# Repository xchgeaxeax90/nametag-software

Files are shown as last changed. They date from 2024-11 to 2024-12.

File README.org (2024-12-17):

#+title: Wisp Light-up Nametag

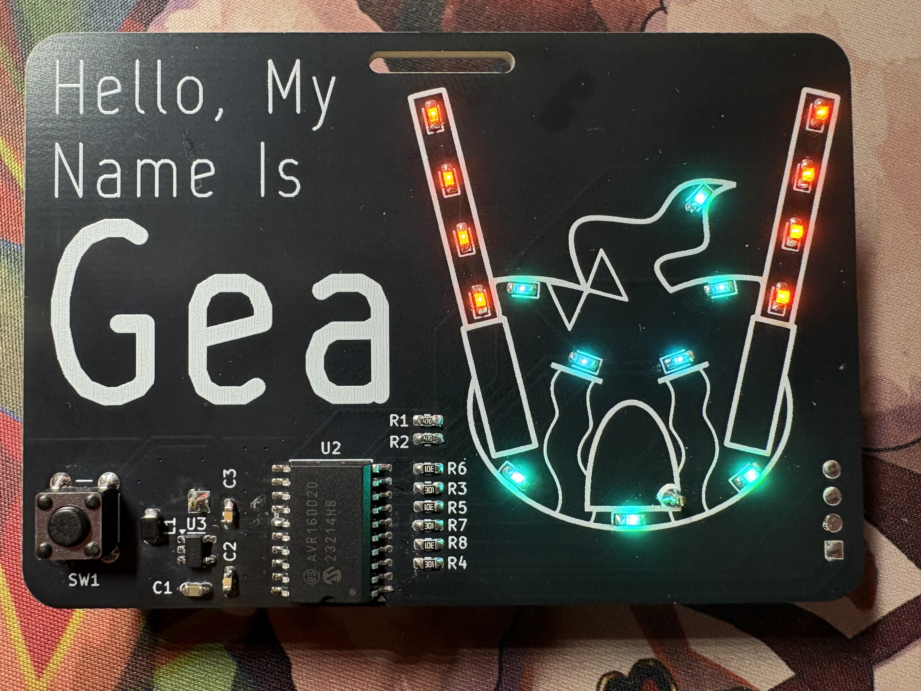
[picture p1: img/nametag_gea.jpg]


This repository contains the PCB design and software for the light up
nametag I gave out at AWA. Gerbers for the blank badge I gave out are
available, and the Kicad project is available for you to modify the
name silkscreened onto the PCB if you would like as well.

But first:
** Crushing Your Expectations
This project involves PCB manufacturing, surface mount soldering, and
flashing firmware onto a microcontroller. While I am able to offer
guidance and suggestions on how to do these things, this is not a step
by step tutorial on how to build your own badge. If you have never
soldered before and have not worked with a bare metal microcontroller,
this project may not be for you.

** PCB
PCBs were ordered from JLCPCB. If you would like to build the blank
nametag, take ~pcb_outputs/nametag_blank.zip~ and upload it to
[[https://jlcpcb.com/][JLCPCB's PCB quote page]]

I would recommend selecting "Black" for PCB color, "Remove Mark" for
Mark on PCB, and leaving everything else default.
The PCB quote should come out to between $2-$4. Pick a shipping option
and order.

*** Custom PCBs
 - Download and install [[https://www.kicad.org/][Kicad]]
 - Open Kicad, then open ~pcb/nametag.kicad_pro~.
 - Click the green button labeled "PCB Editor"
 - Double click on the text on the left to edit it
   - When done, make sure any text you modified or added is on the
 F.Silkscreen layer, it should appear a teal blue.
 - Click File->Fabrication Outputs->Gerbers...
   - Select a directory to export the PCB data to in "Output Directory"
   - Leave the all the checkboxes as they are
   - Click "Plot" on the bottom right
   - Before closing the dialogue box, click "Generate Drill Files..."
     on the bottom row
   - Leave all settings on the new dialogue as default, click
     "Generate Drill File"
   - Close both dialogue boxes
 - Zip up the directory you created in the previous steps. It should
   contain the following:

#+begin_src
nametag-B_Cu.gbr
nametag-B_Mask.gbr
nametag-B_Paste.gbr
nametag-B_Silkscreen.gbr
nametag-Edge_Cuts.gbr
nametag-F_Cu.gbr
nametag-F_Mask.gbr
nametag-F_Paste.gbr
nametag-F_Silkscreen.gbr
nametag-job.gbrjob
nametag-NPTH.drl
nametag-PTH.drl
#+end_src

 - Upload the zip to JLCPCB as described above for the blank PCB

** Parts
An interactive HTML BOM is available in pcb/bom/

My digikey order export is below if that is better for some people.

| Index | DigiKey Part #                  | Manufacturer Part Number | Description                      | Quantity |
|-------+---------------------------------+--------------------------+----------------------------------+----------|
|     1 | 150-AVR16DD20-I/SO-ND           | AVR16DD20-I/SO           | IC MCU 8BIT 16KB FLASH 20SOIC    |        1 |
|     2 | SMLD12E3N1WT86CT-ND             | SMLD12E3N1WT86           | LED BLUE-GREEN DIFFUSED 1608 SMD |        6 |
|     3 | 160-1434-1-ND                   | LTST-C190KFKT            | LED ORANGE CLEAR CHIP SMD        |        8 |
|     4 | 2223-TS02-66-43-BK-160-LCR-D-ND | TS02-66-43-BK-160-LCR-D  | SWITCH TACTILE SPST-NO 0.05A 12V |        1 |
|     5 | 732-4971-1-ND                   | 150060GS75000            | LED GREEN CLEAR 0603 SMD         |        6 |
|     6 | 36-2466-ND                      | 2466                     | BATTERY HOLDER AAA PC PIN        |        1 |
|     7 | 846-SMLD12E2N1WT86CT-ND         | SMLD12E2N1WT86           | LED BLUE-GREEN DIFFUSED 1608 SMD |        2 |
|     8 | 296-52012-1-ND                  | TPS613226ADBVR           | IC REG BOOST 3.6V 1.6A SOT23-5   |        1 |
|     9 | 4713-GMC10X5R226M10NTCT-ND      | GMC10X5R226M10NT         | CAP0603 X5R 22UF 20% 10V         |        1 |
|    10 | 3526-WIP201612S-2R2MLDGCT-ND    | WIP201612S-2R2MLDG       | POWER INDUCTOR 2016 2.2UH 20% DC |        1 |
|    11 | 1292-WR06X470JTLCT-ND           | WR06X470 JTL             | RES 47 OHM 5% 1/10W 0603         |        2 |
|    12 | 300 Ohm 0603 Resistor           | Pick one                 | It doesn't matter                |        6 |
|    13 | 0.1uF 0603 X7R Capacitor        | Pick one                 | At least 6V                      |        2 |

The digikey order above lists 3 green LEDs:
 - SMLD12E3N1WT86 in index 2 - 496nm LED
 - SMLD12E2N1WT86 in index 7 - 505nm LED
 - 150060GS75000  in index 5 - 520nm LED

I originally bought 3 different types because I didn't know what color
would look good. My preference was to have the 505nm LEDs on the
border of the wisp as they look closest to a mint green. The 496nm
LEDs are closer to a cyan and work well in the eye positions. the
520nm LEDs are a cheaper alternative to 505nm LEDs, but are a much
brighter and harsher green than the 505nm LEDs.

Consider what color LEDs you want where, just keep in mind you will
need 8 total to fill out the wisp

The BOM above also lists out some jelly bean 300 ohm resistors and
0.1uF capacitors, both in 0603 size. If you don't have those already,
pick the cheapest ones

Finally, pay attention to your electronic distributor's price breaks,
especially when ordering for only one nametag. For things like LEDs,
resistors, and capacitors, it's often cheaper to order 10 than 4-9,
and you are quite likely to accidentally lose one or two during
assembly. It also would be a good idea to order an extra TPS613226
boost converter in case you fry it putting the battery in wrong (ask
how I know)

** Assembly

Assemble everything according to the interactive BOM in ~pcb/bom~. Pay
attention to the LED polarity. The green LEDs have a little arrow on
the back, that needs to point towards the closed end on each of the
LED footprints. Similarly, the orange LEDs have a little extra tab of
metal on the back, that again needs to face the closed end on the
silkscreen for each of the LED footprints.

Make sure to attach the battery holder to the back side of the PCB,
and ensure it's facing the right polarity

Do not populate the J1 connector, for programming it's far easier to
just jam wires into the holes for a minute instead of worrying about
desoldering a programming header when you want to actually wear the badge

** Programming

The AVR16DD used in this project uses Microchip's new Universal
Programming and Debug Interface (UPDI). While very convenient as it
only uses one pin, programmers for it are not super common. However,
it's not too difficult to build your own:

 - If you have an arduino or other older AVR development board: https://github.com/ElTangas/jtag2updi
   - Be careful with this as the nametag circuit runs on 3.6V, not
     5V. You may need a level shifter and definitely at least need the
     resistor shown in this guide
 - If you have an extra $7, this looks pretty convenient: https://www.adafruit.com/product/5879
 - If you have an FTDI, CP2102, CH340, or other UART dongle, you can
   build an UPDI programmer using the information here https://github.com/SpenceKonde/AVR-Guidance/blob/master/UPDI/jtag2updi.md
   - This is what I did here, I used an FT232H cable with a 5k
     resistor between FT232H TX and the UPDI pin of the
     microcontroller. FT232H RX is directly connected to the UPDI pin
     of the microcontroller
   - Pay attention to the voltage levels output by the UART dongle, as
     again this circuit runs on 3.6V not 5V.

Connect the UPDI pin to the topmost pin of J1 (Pin 4), and ground to
the second pin from the top of J1 (Pin 3)

Download and install [[https://github.com/avrdudes/avrdude][avrdude]]

Navigate to the src/ folder

Run:

#+begin_src
avrdude -c serialupdi -P /dev/ttyUSB0 -p avr16dd20 -B 115200 -U flash:w:main.hex:i
#+end_src

Replace ~-c serialupdi~ with ~-c jtag2updi~ if using the arduino updi
method.
Replace ~-P /dev/ttyUSB0~ with the path to your serial port
Lower ~-B 115200~ if having issues with flaky programming

If successful, your badge should begin flashing

Some method of affixing the nametag to your body will be needed. A
slot is available on the top of the PCB for affixing to a
lanyard. Alternatively (this is what I did) a
[[https://www.ebay.com/itm/183618333854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][magnetic nametag holder]] or pin should be used

** Modifying the source code
LMAO good luck

Install
[[https://avrdudes.github.io/avr-libc/avr-libc-user-manual/install_tools.html][avr-gcc,
avr-binutils, and avr-libc]] -
these will come preinstalled with the arduino IDE if you can figure
out how to access them.

Install [[https://www.gnu.org/software/make/][Make]]. This may come with
Git bash on windows and is almost certainly in your package manager on
Linux.

Navigate to ~src/~ and run ~make~

Run ~make prog~ to program the microcontroller

** Operation

To cycle animations, quickly tap the button

To change the brightness, hold the button for ~3 seconds and
release. The LEDs should turn on continuously. Tap the button to
change the brightness, then press and hold for ~3 seconds and release
again to go back to the animation mode

To turn off, push and hold the button until the LEDs turn off

To turn back on, tap the button again

When storing for a long period of time (weeks, months), it is
recommended to remove or disconnect the battery. The system does not
actually shut off when powered off, instead the microcontroller turns
off all the LEDs and enters into a deep sleep mode. However, the boost
converter powering the circuit remains on, drawing a tiny amount of
power. Over a long period of time (months), this will drain the battery.

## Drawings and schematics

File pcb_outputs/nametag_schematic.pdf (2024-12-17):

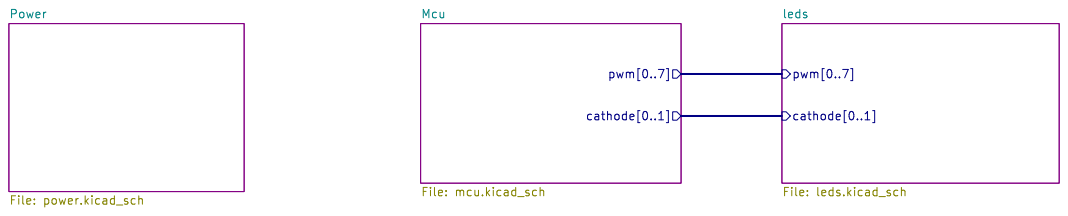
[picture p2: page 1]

cathode[0..1] Mcu File: mcu.kicad_sch Power File: power.kicad_sch

Id: 1/4 Title: File: nametag.kicad_sch Sheet: /

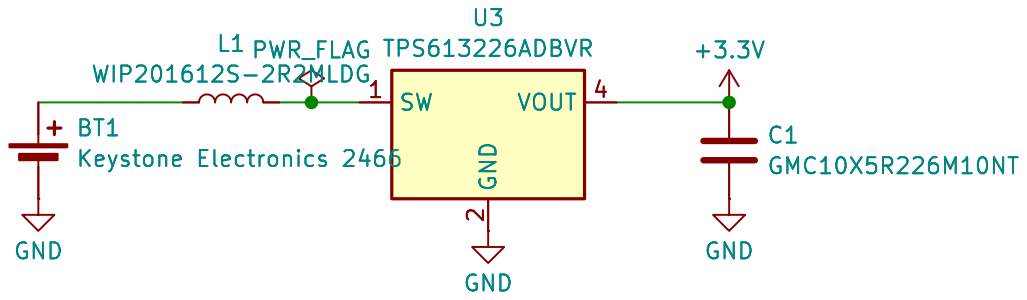
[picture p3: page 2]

Id: 2/4 Title: File: power.kicad_sch Sheet: /Power/

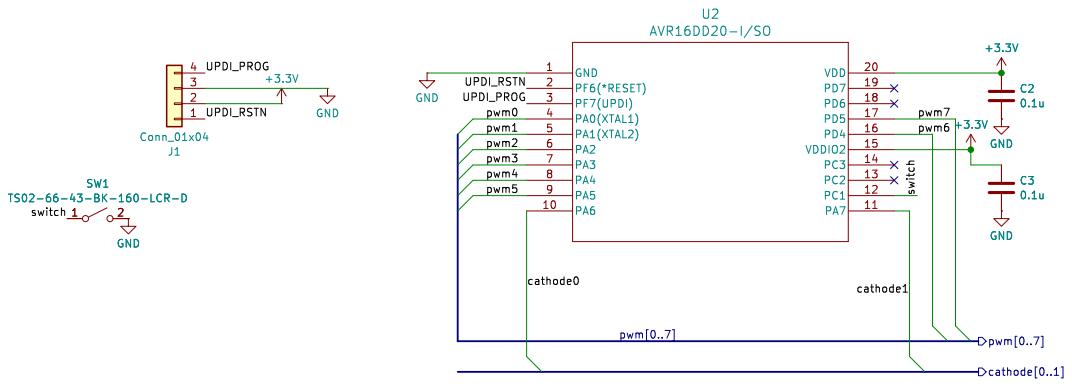
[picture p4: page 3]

Id: 3/4 Title: File: mcu.kicad_sch Sheet: /Mcu/

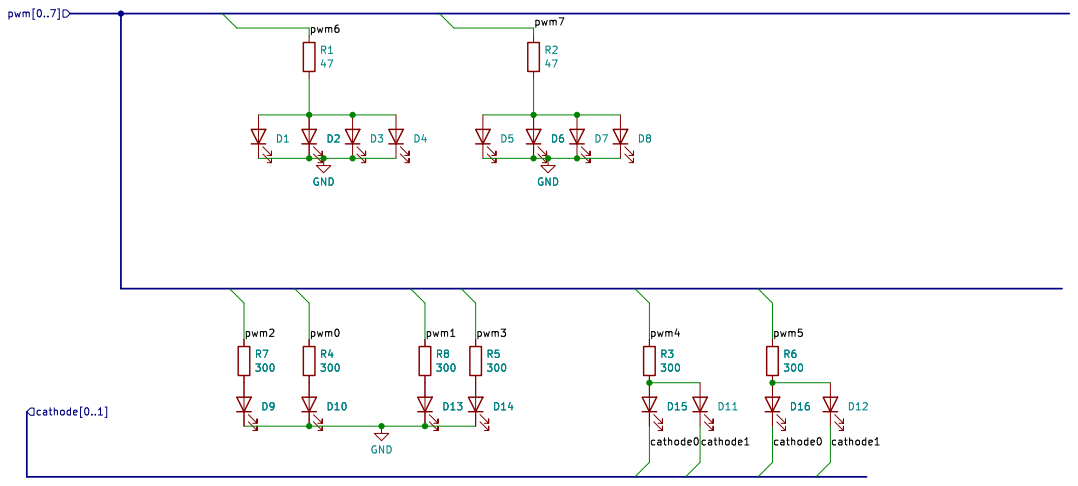
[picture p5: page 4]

Id: 4/4 Title: File: leds.kicad_sch Sheet: /leds/ R3

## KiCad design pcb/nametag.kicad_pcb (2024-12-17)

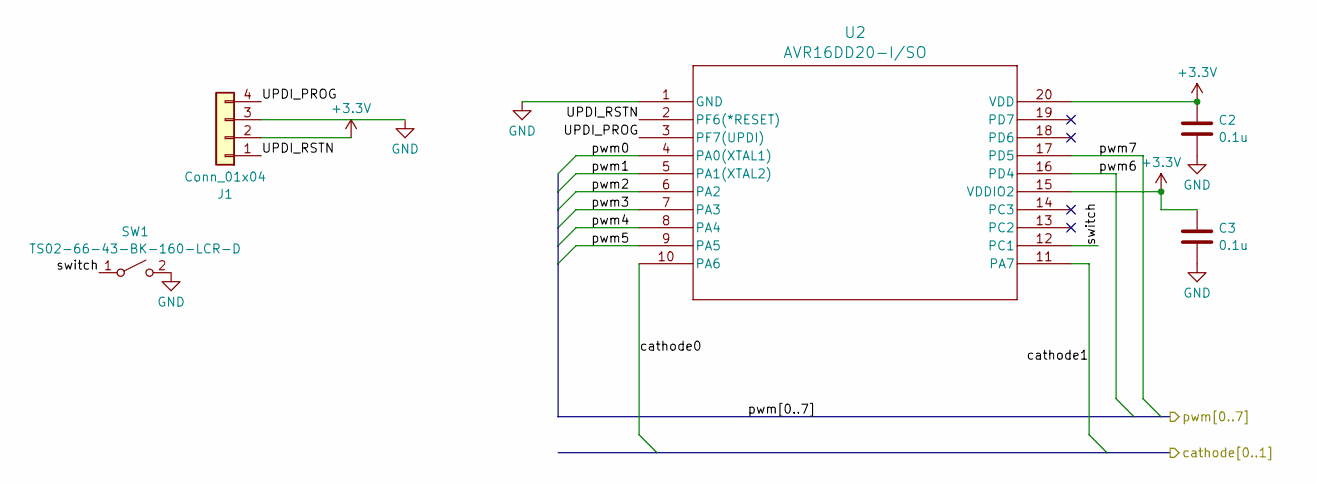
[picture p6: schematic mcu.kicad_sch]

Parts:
C2, C3: 0.1u; C_0603_1608Metric_Pad1.08x0.95mm_HandSolder
J1: Conn_01x04; PinSocket_1x04_P2.54mm_Vertical
SW1: TS02-66-43-BK-160-LCR-D; SW_PUSH_6mm_H4.3mm
U2: AVR16DD20-I/SO; SOIC-20W_7.5x12.8mm_P1.27mm

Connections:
+3.3V: C2.1, C3.1, J1.2, U2.15 (VDDIO2), U2.20 (VDD); also elsewhere on the board
/Mcu/UPDI_PROG: J1.4, U2.3 (PF7(UPDI))
/Mcu/UPDI_RSTN: J1.1, U2.2 (PF6(*RESET))
/Mcu/cathode0: U2.10 (PA6); also elsewhere on the board
/Mcu/cathode1: U2.11 (PA7); also elsewhere on the board
/Mcu/pwm0: U2.4 (PA0(XTAL1)); also elsewhere on the board
/Mcu/pwm1: U2.5 (PA1(XTAL2)); also elsewhere on the board
/Mcu/pwm2: U2.6 (PA2); also elsewhere on the board
/Mcu/pwm3: U2.7 (PA3); also elsewhere on the board
/Mcu/pwm4: U2.8 (PA4); also elsewhere on the board
/Mcu/pwm5: U2.9 (PA5); also elsewhere on the board
/Mcu/pwm6: U2.16 (PD4); also elsewhere on the board
/Mcu/pwm7: U2.17 (PD5); also elsewhere on the board
/Mcu/switch: SW1.1 (A), U2.12 (PC1)
GND: C2.2, C3.2, J1.3, SW1.2 (B), U2.1 (GND); also elsewhere on the board

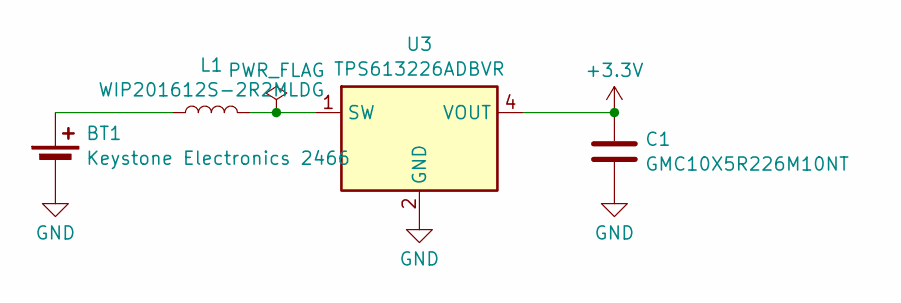
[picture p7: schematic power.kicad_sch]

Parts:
BT1: Keystone Electronics 2466; BatteryHolder_Keystone_2466_1xAAA
C1: GMC10X5R226M10NT; C_0603_1608Metric_Pad1.08x0.95mm_HandSolder
L1: WIP201612S-2R2MLDG; L_0805_2012Metric_Pad1.15x1.40mm_HandSolder
U3: TPS613226ADBVR; SOT-23-5

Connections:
+3.3V: C1.1, U3.4 (VOUT); also elsewhere on the board
GND: BT1.2 (-), C1.2, U3.2 (GND); also elsewhere on the board
unnamed: BT1.1 (+), L1.1
unnamed: L1.2, U3.1 (SW)

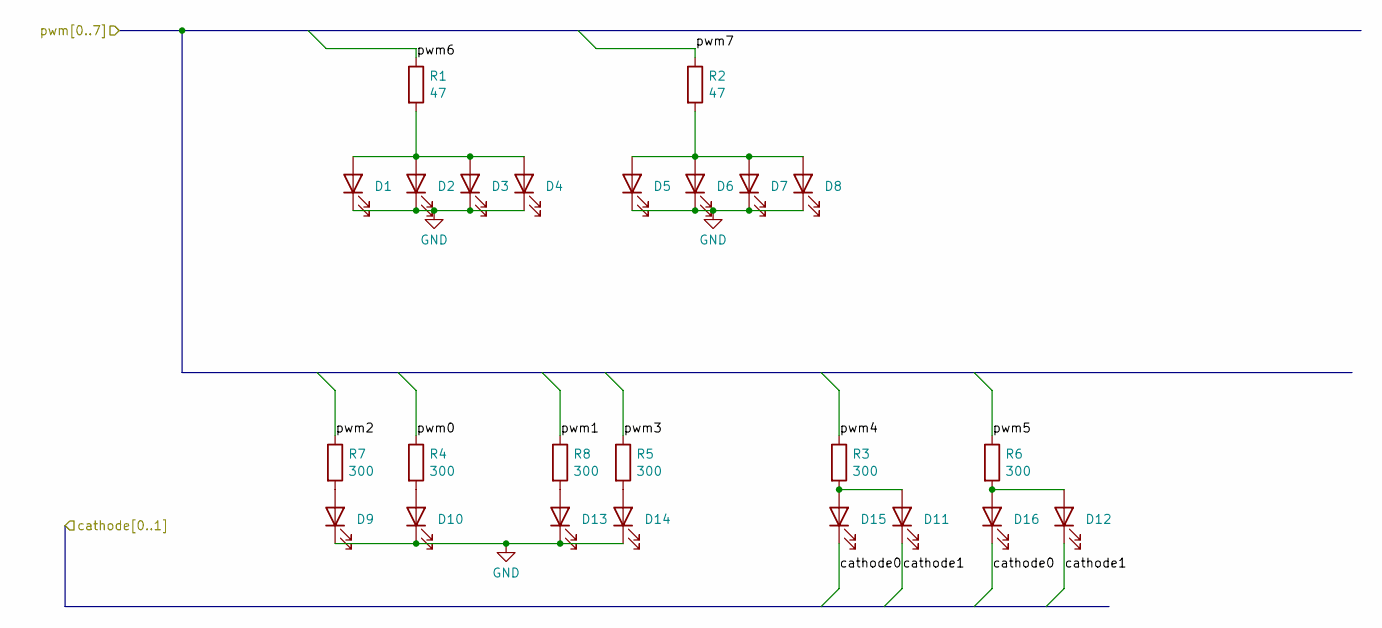
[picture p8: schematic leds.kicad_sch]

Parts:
D1, D2, D3, D4, D5, D6, D7, D8: LTST-C190KFKT; LED_0603_1608Metric_Pad1.05x0.95mm_HandSolder
D9, D10, D11, D12, D13, D14: SMLD12E3N1WT86; LED_0603_1608Metric_Pad1.05x0.95mm_HandSolder
D15, D16: SMLD12E2N1WT86; LED_0603_1608Metric_Pad1.05x0.95mm_HandSolder
R1, R2: 47; R_0603_1608Metric_Pad0.98x0.95mm_HandSolder
R3, R4, R5, R6, R7, R8: 300; R_0603_1608Metric_Pad0.98x0.95mm_HandSolder

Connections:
/Mcu/cathode0: D15.1 (K), D16.1 (K); also elsewhere on the board
/Mcu/cathode1: D11.1 (K), D12.1 (K); also elsewhere on the board
/Mcu/pwm0: R4.1; also elsewhere on the board
/Mcu/pwm1: R8.1; also elsewhere on the board
/Mcu/pwm2: R7.1; also elsewhere on the board
/Mcu/pwm3: R5.1; also elsewhere on the board
/Mcu/pwm4: R3.1; also elsewhere on the board
/Mcu/pwm5: R6.1; also elsewhere on the board
/Mcu/pwm6: R1.1; also elsewhere on the board
/Mcu/pwm7: R2.1; also elsewhere on the board
GND: D1.1 (K), D2.1 (K), D3.1 (K), D4.1 (K), D5.1 (K), D6.1 (K), D7.1 (K), D8.1 (K), D9.1 (K), D10.1 (K), D13.1 (K), D14.1 (K); also elsewhere on the board
unnamed: D1.2 (A), D2.2 (A), D3.2 (A), D4.2 (A), R1.2
unnamed: D5.2 (A), D6.2 (A), D7.2 (A), D8.2 (A), R2.2
unnamed: D9.2 (A), R7.2
unnamed: D10.2 (A), R4.2
unnamed: D11.2 (A), D15.2 (A), R3.2
unnamed: D12.2 (A), D16.2 (A), R6.2
unnamed: D13.2 (A), R8.2
unnamed: D14.2 (A), R5.2

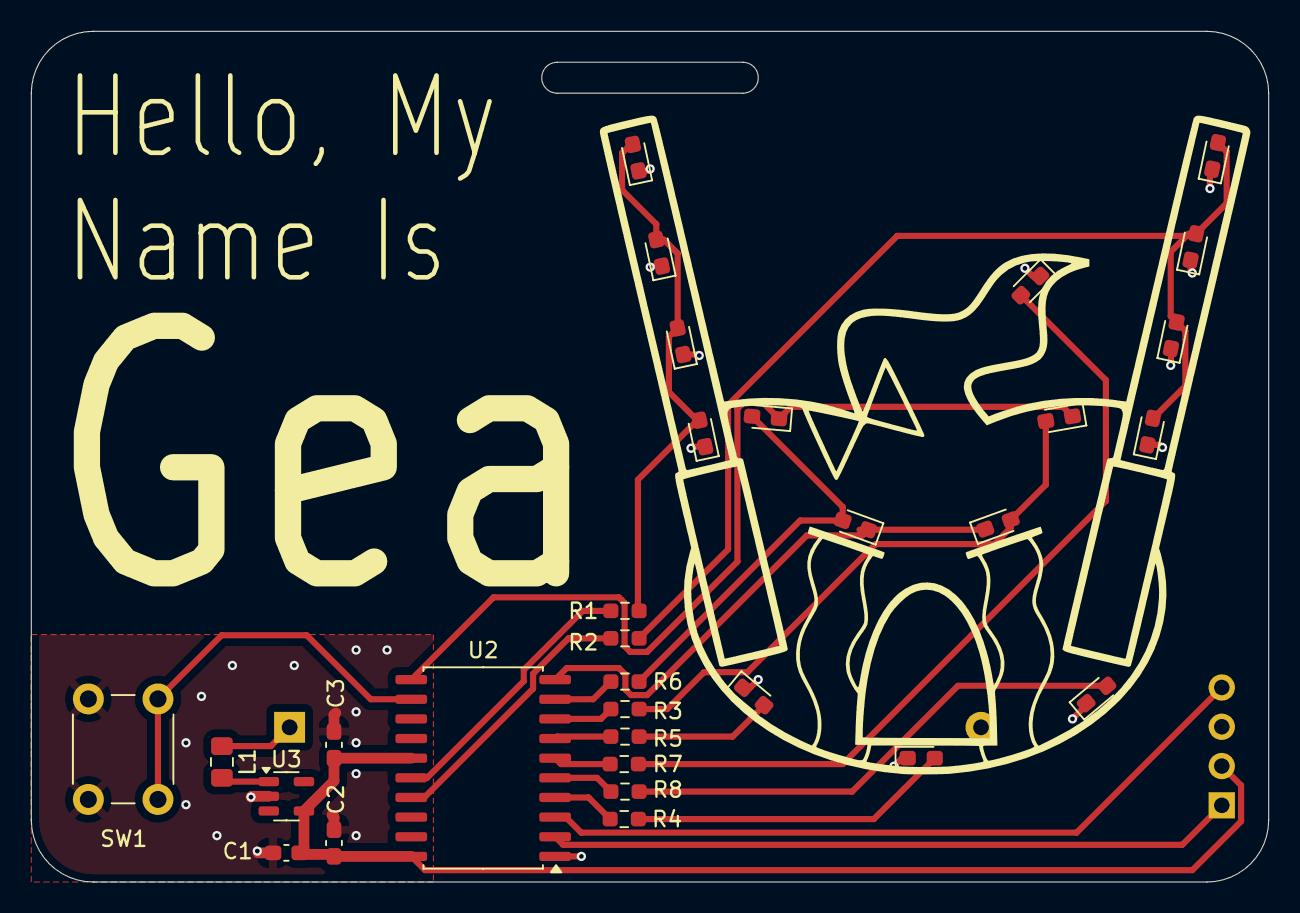
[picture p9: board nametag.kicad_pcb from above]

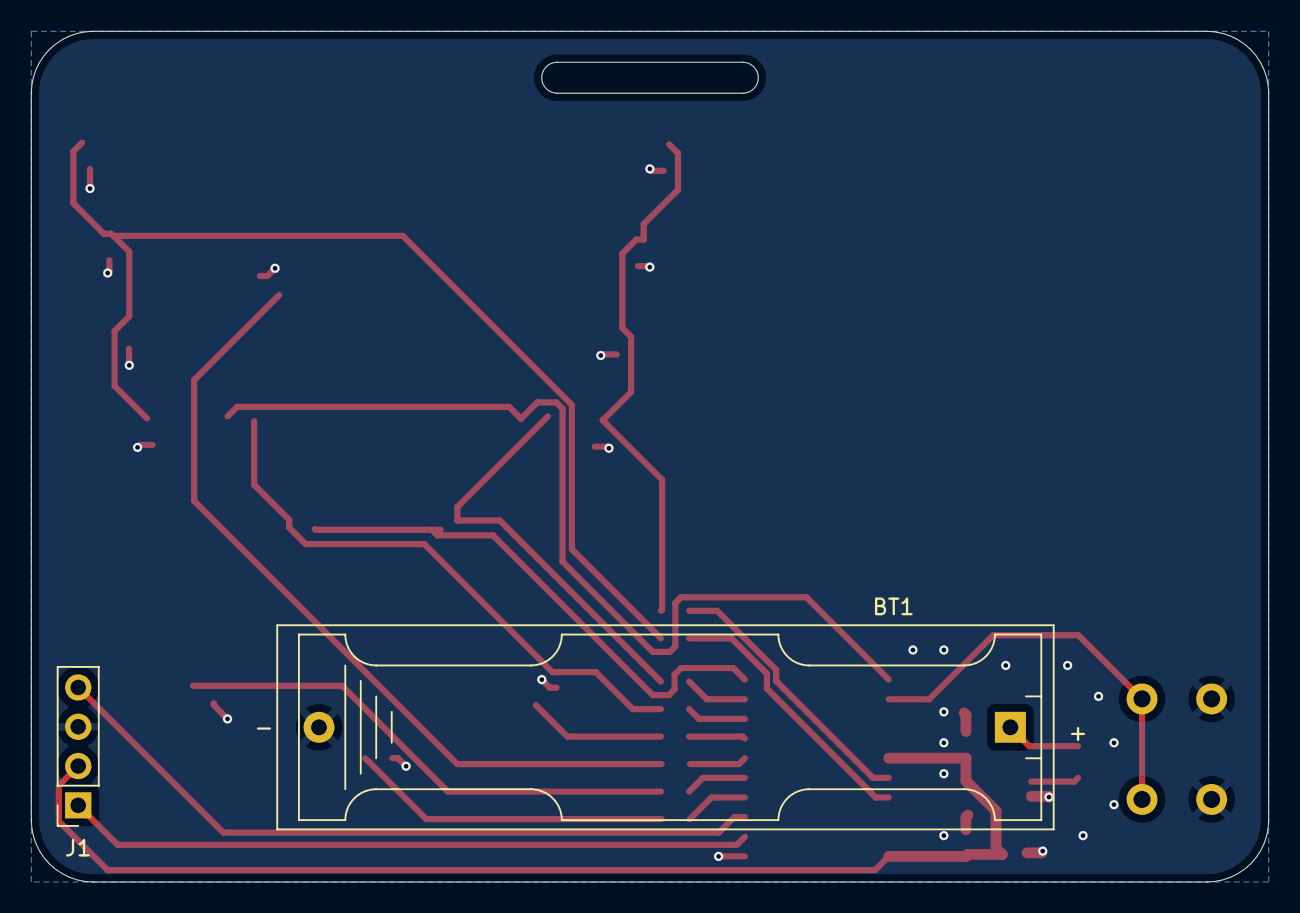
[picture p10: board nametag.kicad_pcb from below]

Board: 2 copper layers, 80.0 x 55.0 mm, 33 parts (2 on the bottom side), 25 nets.

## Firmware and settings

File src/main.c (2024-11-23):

#include <avr/io.h>
#include <avr/interrupt.h>
#include <avr/sleep.h>
#include <util/delay.h>
#include "pwm.h"
#include "pins.h"
#include "timer.h"
#include "animation.h"
#include "state_machine.h"


void init_clock();
volatile uint16_t button_timeout = 0;
volatile uint8_t button_state = 0;
void poll_button(void){
    if(BTN_PORT.IN & BTN_bm){
	if(!button_state){
	    button_timeout = 0;
	} else {
	    button_timeout += 1;
	}
	button_state = 1;
    } else {
	button_state = 0;
    }
}

// Called periodically by TCB0 to update the multiplexing for the eyes and top LEDs
static volatile uint8_t eye_en = 0;

ISR(TCB0_INT_vect) {
    poll_button();
    CATHODE_PORT.OUTSET = CAT0_bm | CAT1_bm;
    // Toggle the multiplex driver pins
    if(update_animation()){

	write_pwm(&animation_ptr->pwm_settings);
    }
    eye_en = ~eye_en;
    // Set the actual multiplex pins on the TCA interrupt, so they're synced to the PWM period
    TCA0.SPLIT.INTFLAGS = TCA_SPLIT_HUNF_bm;
    TCA0.SPLIT.INTCTRL = TCA_SPLIT_HUNF_bm;
    TCB0.INTFLAGS = TCB_CAPT_bm;
}

ISR(TCA0_HUNF_vect) {
    if(eye_en){
	CATHODE_PORT.OUTCLR = CAT0_bm;
    } else {
	CATHODE_PORT.OUTCLR = CAT1_bm;
    }
    write_pwm_multiplexed(&animation_ptr->pwm_settings, eye_en);
    TCA0.SPLIT.INTFLAGS = TCA_SPLIT_HUNF_bm;
    TCA0.SPLIT.INTCTRL = 0;
}

void deep_sleep(void){
    stop_pwm();
    disable_pins();
    disable_timer();
    enable_button_interrupt();
    set_sleep_mode(SLEEP_MODE_PWR_DOWN);
    sleep_mode();
    disable_button_interrupt();
    init_pins();
    init_timer();
    init_pwm();
}

int main(void){
    init_clock();

    init_pins();
    //init_button_interrupt();

    init_pwm();

    init_timer();

    sei();
    while(1){
	cli();
	uint16_t timeout = button_timeout;
	uint8_t state = button_state;
	sei();
	if(state == 0 && timeout > 20 && timeout < 300){
	    short_button_press();
	}
	if(state == 0 && timeout >= 300 && timeout < 700){
	    long_button_press();
	}
	/* use == instead of >= so as not to continuously call
	select_off_animation() every time we poll the button
	state. Doing so causes update_animation to never fire because
	the animation timeout is never reached */
	if(state == 1 && timeout == 700){
	    select_off_animation();
	}
	if(state == 0 && timeout >= 700){
	    deep_sleep();
	}
	if(state == 0 && timeout != 0){
	    cli();
	    button_timeout = 0;
	    sei();
	}
	set_sleep_mode(SLEEP_MODE_IDLE);
	sleep_mode();
    }
}


void init_clock(void){
    // Select the HF RC oscillator
    _PROTECTED_WRITE(CLKCTRL.MCLKCTRLA, CLKCTRL_CLKSEL_OSCHF_gc);
    // Wait until clock switch is over
    while(CLKCTRL.MCLKSTATUS & CLKCTRL_SOSC_bm) {}

    // Select 1MHz, no run standby
    _PROTECTED_WRITE(CLKCTRL.OSCHFCTRLA, CLKCTRL_FRQSEL_1M_gc);

}

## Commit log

2024-11-04 Separate out pwm functions into their own file
2024-11-04 Set timer B as periodic interrupt, drive the multiplex select pins on an interrupt
2024-11-04 Configure a pin change update for the button input
2024-11-05 Working pwm on both face and light sticks
2024-11-05 Fix animation multiplex bug
    [main.c]
2024-11-06 Tweaks to hopefully reduce power consumption
2024-11-09 Move ISR function out of timer.c
2024-11-23 Make power off take effect immediately
2024-12-17 Add kicad project to repo
    [leds.kicad_sch, mcu.kicad_sch, nametag.kicad_pcb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]
2024-12-17 Add gerber outputs
    [nametag-B_Cu.gbr, nametag-B_Mask.gbr, nametag-B_Paste.gbr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]
2024-12-17 Add PDF schematic and description of how to affix nametag
